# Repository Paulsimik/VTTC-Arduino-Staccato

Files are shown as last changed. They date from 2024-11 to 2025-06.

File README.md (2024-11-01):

# VTTC-Arduino-Staccato
Interrupter for VTTC - Kicad project

I'm sharing this interrupter for inspiration if you want to build your own. You may need to modify the wiring diagram or program for proper function. I take no responsibility for any property damage or personal injury.




YouTube #1</br>
Video1 (https://www.youtube.com/watch?v=uaf3k1Z0Gr8)

YouTube #2</br>
Video2 (https://www.youtube.com/watch?v=Orlu5OpqwGU)

YouTube #3</br>
Video3 (https://www.youtube.com/watch?v=_JIQWXnwYew)

YouTube #4</br>
Video4 (https://www.youtube.com/watch?v=DjzjCPVujho)

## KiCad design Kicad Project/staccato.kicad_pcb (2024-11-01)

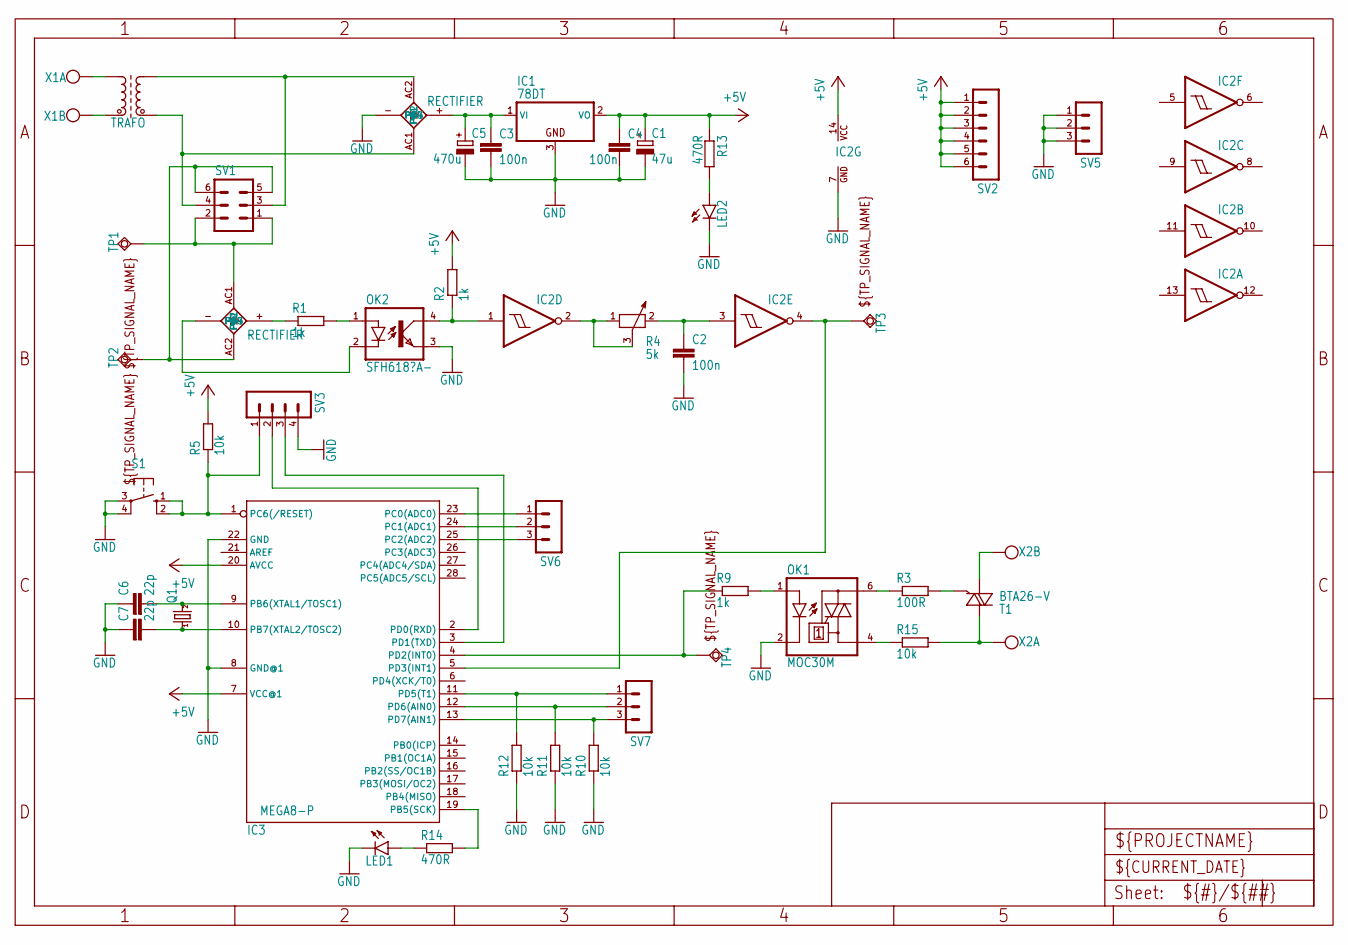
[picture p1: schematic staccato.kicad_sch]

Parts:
C1: 47u; E2,5-6
C2: 100n; C050-025X075
C3, C4: 100n; C0805
C5: 470u; E5-10,5
C6, C7: 22p; C0805
IC1: 78DT; TO252
IC2: 7414N; DIL14
IC3: MEGA8-P; DIL28-3
LED1, LED2: LED3MM
OK1: MOC30M; DIL06
OK2: SFH618?A-; DIP4-400
Q1: CRYSTALHC49S; HC49_S
R1, R2, R9: 1k; M0805
R3: 100R; M0805
R4: 5k; PT-10
R5, R10, R11, R12, R15: 10k; M0805
R13, R14: 470R; M0805
S1: 10-XX; B3F-10XX
SV1: MA03-2
SV2: MA06-1
SV3: MA04-1
SV5, SV6, SV7: MA03-1
T1: BTA26-V; TOP3S-1
TP1, TP2, TP3, TP4: TPSQPAD1-13Y; P1-13Y
U$1: TRAFO
U$2, U$4: RECTIFIER
X1, X2: W237-102

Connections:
+5V: C1.+, C4.1, IC1.2 (VO), IC2.14 (VCC), IC3.7 (VCC@1), IC3.20 (AVCC), R2.2, R5.2, R13.1, SV2.1, SV2.2, SV2.3, SV2.4, SV2.5, SV2.6
GND: C1.-, C2.2, C3.2, C4.2, C5.-, C6.1, C7.1, IC1.3 (GND), IC2.7 (GND), IC3.8 (GND@1), IC3.22 (GND), LED1.K (C), LED2.K (C), OK1.2 (C), OK2.3 (EMIT), R10.1, R11.1, R12.1, S1.3, S1.4 (P1), SV3.4, SV5.1, SV5.2, SV5.3, U$2.-
unnamed: SV1.3, U$1.P$3 (A2), U$2.AC2
unnamed: SV1.4, U$1.P$4 (E2), U$2.AC1
unnamed: U$1.P$1 (A1), X1.1
unnamed: U$1.P$2 (E1), X1.2
unnamed: OK2.1 (A), R1.2
unnamed: IC2.1 (I), OK2.4 (COL), R2.1
unnamed: OK1.6 (A2), R3.1
unnamed: R3.2, T1.G
unnamed: R15.2, T1.A2, X2.1
unnamed: T1.A1, X2.2
unnamed: IC2.2 (O), R4.1, R4.3
unnamed: C2.1, IC2.3 (I), R4.2
unnamed: R1.1, U$4.+
unnamed: OK2.2 (C), U$4.-
unnamed: C3.1, C5.+, IC1.1 (VI), U$2.+
unnamed: C6.2, IC3.9 (PB6(XTAL1/TOSC1)), Q1.2
unnamed: IC3.1 (PC6(/RESET)), R5.1, S1.1 (S), S1.2 (S1), SV3.1
unnamed: C7.2, IC3.10 (PB7(XTAL2/TOSC2)), Q1.1
unnamed: IC3.23 (PC0(ADC0)), SV6.1
unnamed: IC3.24 (PC1(ADC1)), SV6.2
unnamed: IC3.25 (PC2(ADC2)), SV6.3
unnamed: OK1.1 (A), R9.2
unnamed: IC3.4 (PD2(INT0)), R9.1, TP4.TP
unnamed: IC3.11 (PD5(T1)), R12.2, SV7.1
unnamed: IC3.12 (PD6(AIN0)), R11.2, SV7.2
unnamed: IC3.13 (PD7(AIN1)), R10.2, SV7.3
unnamed: LED2.A, R13.2
unnamed: IC3.19 (PB5(SCK)), R14.2
unnamed: LED1.A, R14.1
unnamed: SV1.5, SV1.6, TP2.TP, U$4.AC2
unnamed: SV1.1, SV1.2, TP1.TP, U$4.AC1
unnamed: IC2.4 (O), IC3.5 (PD3(INT1)), TP3.TP
unnamed: OK1.4 (A1), R15.1
unnamed: IC3.2 (PD0(RXD)), SV3.2
unnamed: IC3.3 (PD1(TXD)), SV3.3

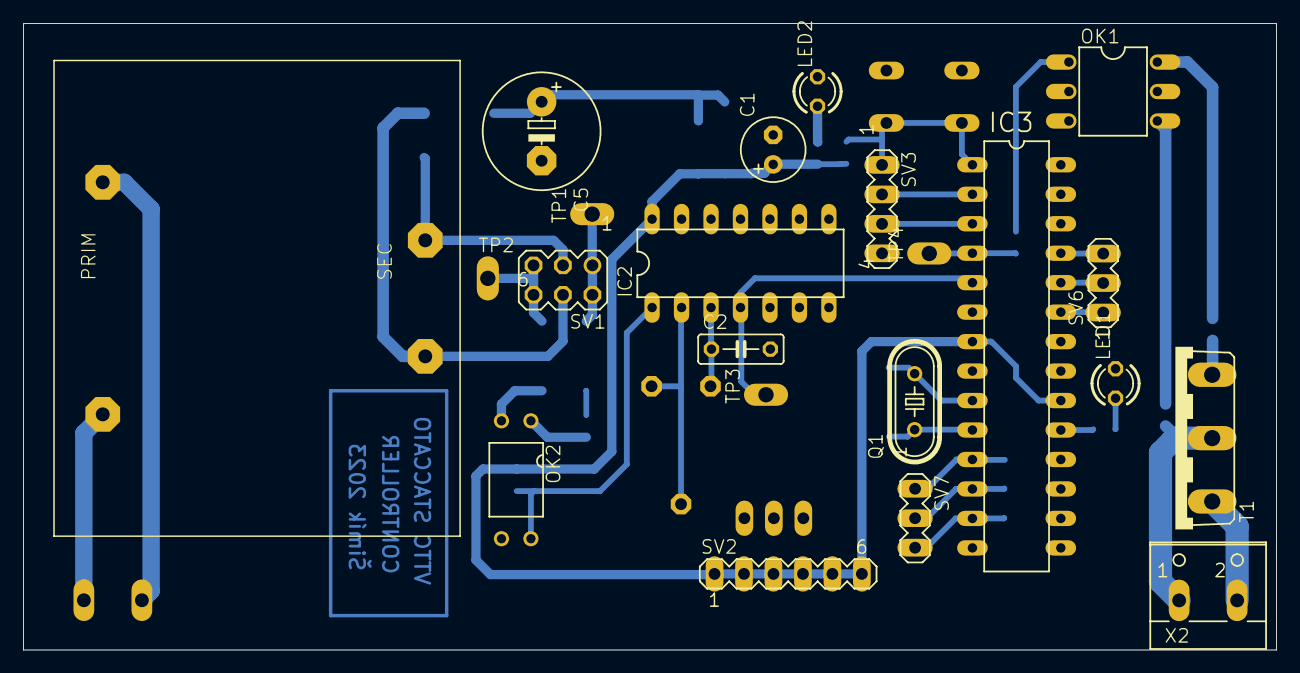
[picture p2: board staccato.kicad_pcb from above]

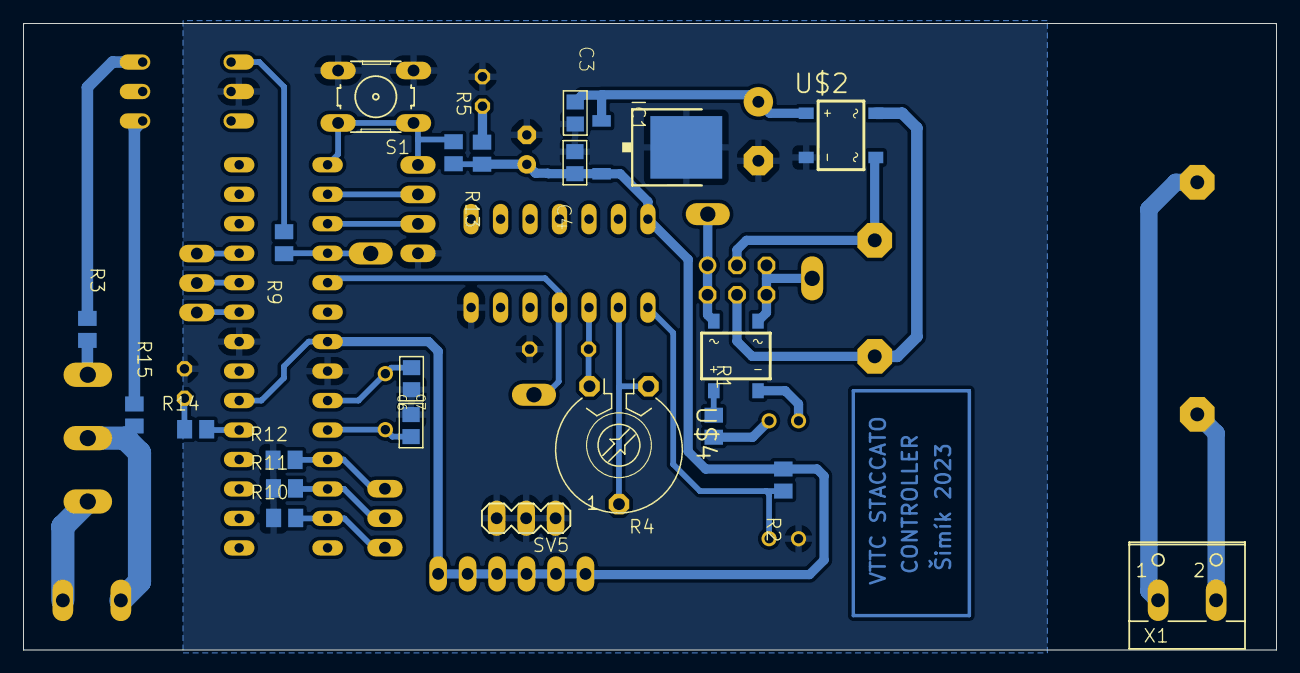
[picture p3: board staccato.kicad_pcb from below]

Board: 2 copper layers, 108.0 x 54.0 mm, 44 parts (22 on the bottom side), 37 nets.

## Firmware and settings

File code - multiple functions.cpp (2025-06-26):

//#############################
// VTTC Staccato
// Version 1.2
// By Paul Simik
//#############################

//  1.0
//  - Program release
//
//  1.1
//  - Added option pulse delay for Standart mode - pot2
//  - Added Falling ARSG Mode
//  - Added Bidirectional ARSG Mode
//  - Small fixes
//  1.2
//  - Optimalizing

#include <Arduino.h>

#define INPUT_PIN 3
#define OUTPUT_PIN 2
#define OUTPUT_LED 13
#define POT_1 A0
#define POT_2 A1
#define POT_3 A2
#define BTN_1 5
#define BTN_2 6
#define BTN_3 7
#define BTN_4 8

enum modeType
{
  MODE_STANDART,
  MODE_BURST,
  MODE_RISING,
  MODE_FALLING,
  MODE_BIDIRECTIONAL
};

enum modeType currMode = MODE_STANDART;

int pot1 = 0;
int pot2 = 0;
int pot3 = 0;

bool btn_1 = false;
bool btn_2 = false;
bool btn_3 = false;
bool btn_4 = false;

int i = 9700;
int x = 0;
int y = 0;
int z = 0;

bool pulse = false;
bool rising = true;

void Output();
void FallingMode();
void FallingControl();
void RisingMode();
void RisingControl();
void BidirectionalMode();
void BidirectionalControl();
void BurstMode();
void BurstControl();
void StandartMode();
void StandartControl();
void SetOutput(bool output);
void SetupPins();
int SelectMode();

void setup() 
{
  SetupPins();
  attachInterrupt(digitalPinToInterrupt(INPUT_PIN), Output, RISING);
}

void loop() 
{
  switch (SelectMode())
  {
    case MODE_BIDIRECTIONAL:  currMode = MODE_BIDIRECTIONAL;    BidirectionalControl(); break;
    case MODE_FALLING:        currMode = MODE_FALLING;          FallingControl();       break;
    case MODE_RISING:         currMode = MODE_RISING;           RisingControl();        break;
    case MODE_BURST:          currMode = MODE_BURST;            BurstControl();         break;
    case MODE_STANDART:       currMode = MODE_STANDART;         StandartControl();      break;
  }
}

void Output()
{
  switch (currMode)
  {
    case MODE_BIDIRECTIONAL:  BidirectionalMode();  break;
    case MODE_FALLING:        FallingMode();        break;
    case MODE_RISING:         RisingMode();         break;
    case MODE_BURST:          BurstMode();          break;
    case MODE_STANDART:       StandartMode();       break;
  }
}

void FallingMode()
{
  x++;
  if(x >= pot1)
  {
    y += pot2;
    if(y < 9700)
    {
      delayMicroseconds(y);
      SetOutput(1);
      delayMicroseconds(9700 - y);
      SetOutput(0);
    }

    x = 0;
  }

  if(y > pot3)
  {
    y = 0;
  }
}

void FallingControl()
{
  pot1 = map(analogRead(POT_1), 0, 1023, 2, 8); // Frequency
  pot2 = map(analogRead(POT_2), 0, 1023, 500, 50); // Rising steps
  pot3 = map(analogRead(POT_3), 0, 1023, 9000, 20000); // Delay next start
}

void RisingMode()
{
  x++;
  if(x >= pot1)
  {
    i -= pot2;
    if(i > 0)
    {
      delayMicroseconds(i);
      SetOutput(1);
      delayMicroseconds(9700 - i);
      SetOutput(0);
    }

    x = 0;
  }

  if(i < (pot3 * -1))
  {
    i = 9700;
  }
}

void RisingControl()
{
  pot1 = map(analogRead(POT_1), 0, 1023, 2, 8); // Frequency
  pot2 = map(analogRead(POT_2), 0, 1023, 500, 50); // Falling steps
  pot3 = map(analogRead(POT_3), 0, 1023, 200, 20000); // Delay next start
}

void BidirectionalMode()
{
  x++;
  if(x >= pot1)
  {
    if(rising)
    {
      i -= pot2;
      if(i > 0)
      {
        delayMicroseconds(i);
        SetOutput(1);
        delayMicroseconds(9700 - i);
        SetOutput(0);
      }

      x = 0;

      if(i < 500)
      {
        i = 9700;
        rising = false;
      }
    }
    else
    {
      y += pot2;
      if(y < 9700)
      {
        delayMicroseconds(y);
        SetOutput(1);
        delayMicroseconds(9700 - y);
        SetOutput(0);
      }

      x = 0;

      if(y > pot3)
      {
        y = 0;
        rising = true;
      }
    }
  }
}

void BidirectionalControl()
{
  pot1 = map(analogRead(POT_1), 0, 1023, 2, 8); // Frequency
  pot2 = map(analogRead(POT_2), 0, 1023, 500, 50); // Rising steps
  pot3 = map(analogRead(POT_3), 0, 1023, 9000, 30000); // Delay next start
}

void BurstMode()
{
  x++;
  if(x >= pot3)
  {
    z++;
    if(z >= pot2)
    {
      SetOutput(1);
      delayMicroseconds(9500);
      SetOutput(0);
      y++;
      z = 0;
    }

    if(y >= pot1)
    {
      x = 0;
      y = 0;
    }
  }
}

void BurstControl()
{
  pot1 = map(analogRead(POT_1), 0, 1023, 20, 2); // Pulse count
  pot2 = map(analogRead(POT_2), 0, 1023, 2, 10); // Pulse skip
  pot3 = map(analogRead(POT_3), 0, 1023, 10, 100);  // Pulse delay
}

void StandartMode()
{
  x++;
  if(x >= pot1)
  {
    delayMicroseconds(pot2);
    SetOutput(1);
    delayMicroseconds(9700 - pot2);
    SetOutput(0);
    x = 0;
  }
}

void StandartControl()
{
  pot1 = map(analogRead(POT_1), 0, 1023, 2, 100); // Standart Mode pulse skip
  pot2 = map(analogRead(POT_2), 0, 1023, 0, 9700); // Start pulse delay
}

int SelectMode()
{
  if(digitalRead(BTN_1))
    return MODE_BIDIRECTIONAL;
  else if (digitalRead(BTN_2))
    return MODE_RISING;
  else if (digitalRead(BTN_3))
    return MODE_FALLING;
  else if (digitalRead(BTN_4))
    return MODE_BURST;
  else
    return MODE_STANDART;
}

void SetOutput(bool output)
{
  output ? PORTD |= (1 << PIND2) : PORTD &= ~(1 << PIND2);
  output ? PORTB |= (1 << PINB5) : PORTB &= ~(1 << PINB5);
}

void SetupPins()
{
  pinMode(OUTPUT_PIN, OUTPUT);
  pinMode(OUTPUT_LED, OUTPUT);
  pinMode(INPUT_PIN, INPUT);
  pinMode(POT_1, INPUT);
  pinMode(POT_2, INPUT);
  pinMode(POT_3, INPUT);
  pinMode(BTN_1, INPUT);
  pinMode(BTN_2, INPUT);
  pinMode(BTN_3, INPUT);
  pinMode(BTN_4, INPUT);
}

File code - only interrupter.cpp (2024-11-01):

#include <Arduino.h>

#define OUTPUT_PIN PA0
#define INPUT_PIN PB11
#define BPS_PIN PA7

int maxBps = 2;

int i = 0;

void Output_ISR(void);

void setup() 
{
  pinMode(OUTPUT_PIN, OUTPUT);
  pinMode(INPUT_PIN, INPUT);
  pinMode(BPS_PIN, INPUT);
  attachInterrupt(digitalPinToInterrupt(INPUT_PIN), Output_ISR, RISING);
}

void loop() 
{
  maxBps = map(analogRead(BPS_PIN), 0, 1023, 2, 100);
}

void Output_ISR()
{
  i++;
  if(i >= maxBps)
  {
    digitalWrite(OUTPUT_PIN, HIGH);
    delayMicroseconds(9700); //9700 period
    digitalWrite(OUTPUT_PIN, LOW);
    i = 0;
  }
}
